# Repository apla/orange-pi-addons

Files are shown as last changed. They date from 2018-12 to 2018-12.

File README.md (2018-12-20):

# Orange Pi Zero+ H5 Addons

## Hacking Addon

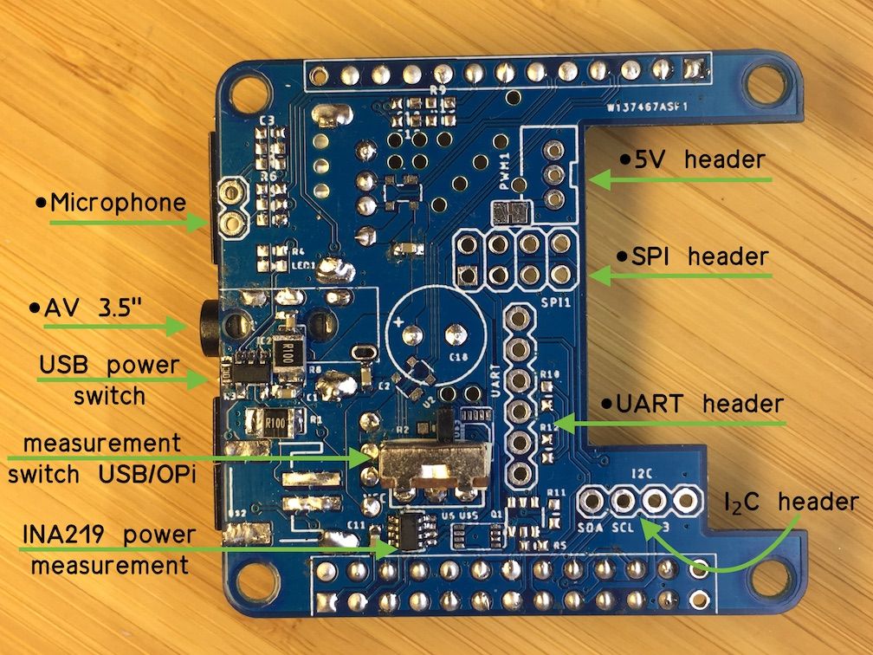
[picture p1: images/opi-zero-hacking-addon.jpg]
Orange Pi Zero Hacking Addon / Shield / Board


## TODO: DeviceTree

[Armbian docs for using overlays](https://docs.armbian.com/User-Guide_Allwinner_overlays/)

https://elinux.org/Device_Tree_Usage

[DTS for OrangePi Zero H2+](https://github.com/torvalds/linux/blob/master/arch/arm/boot/dts/sun8i-h2-plus-orangepi-zero.dts)

[DTS for OrangePi Zero H5](https://github.com/torvalds/linux/blob/master/arch/arm64/boot/dts/allwinner/sun50i-h5-orangepi-zero-plus.dts)

https://forum.armbian.com/topic/8795-next-lts-kernel-419y-allwinner-a10-a20-a64-h2-h3-h5-h6-debugging-party/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

adding voltage regulator

```js
	reg_vdd_cpux: vdd-cpux-regulator {
		compatible = "regulator-gpio";
		regulator-name = "vdd-cpux";
		regulator-type = "voltage";
		regulator-boot-on;
		regulator-always-on;
		regulator-min-microvolt = <1100000>;
		regulator-max-microvolt = <1300000>;
		regulator-ramp-delay = <50>; /* 4ms */

		gpios = <&r_pio 0 6 GPIO_ACTIVE_HIGH>; /* PA6 */
		enable-active-high;
		gpios-states = <0>;
		states = <1100000 0
			  1300000 1>;
	};
```

```js
&cpu0 {
	cpu-supply = <&reg_vdd_cpux>;
};
```

adding usb power switch (https://www.kernel.org/doc/Documentation/devicetree/bindings/regulator/fixed-regulator.txt)

```js
	usb_pwr: usb_pwr {
		compatible = "regulator-fixed";
		regulator-name = "vbus-addon-supply";
		regulator-min-microvolt = <5000000>;
		regulator-max-microvolt = <5000000>;
		gpio = <&r_pio 0 7>;
		regulator-boot-on;
	};
```

[ina219 dt overlay](https://github.com/armbian/sunxi-DT-overlays/blob/master/examples/i2c-ina219.dts)

```js
/dts-v1/;
/plugin/;

/ {
	compatible = "allwinner,sun4i-a10", "allwinner,sun7i-a20", "allwinner,sun8i-h3", "allwinner,sun50i-a64", "allwinner,sun50i-h5";

	fragment@0 {
		target = <&i2c0>;
		__overlay__ {
			#address-cells = <1>;
			#size-cells = <0>;
			ina219@40 {
				compatible = "ti,ina219";
				reg = <0x40>;
				status = "okay";
				shunt-resistor = <100000>;
			};
		};
	};
};
```

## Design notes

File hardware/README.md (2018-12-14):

# HW status: your OPi will burn with flames!

## Hardware issues after manufacture

 * **MAJOR** There is a one short circuit between 5V and GND on USB connector shield
 * 3.5 AV connector placed upside down
 * Current shunt placed after USB, so current meter shows junk after USB power shut down
 * No filtering capacitors for temp and security devices

## What works

 * I2C works fine
 * USB works fine (data, power switching, power metering)

## What untested

 * ESD on USB
 * USB overcurrent indicator
 * UART + UART level shift
 * SPI
 * AV, Mic
 * PWM

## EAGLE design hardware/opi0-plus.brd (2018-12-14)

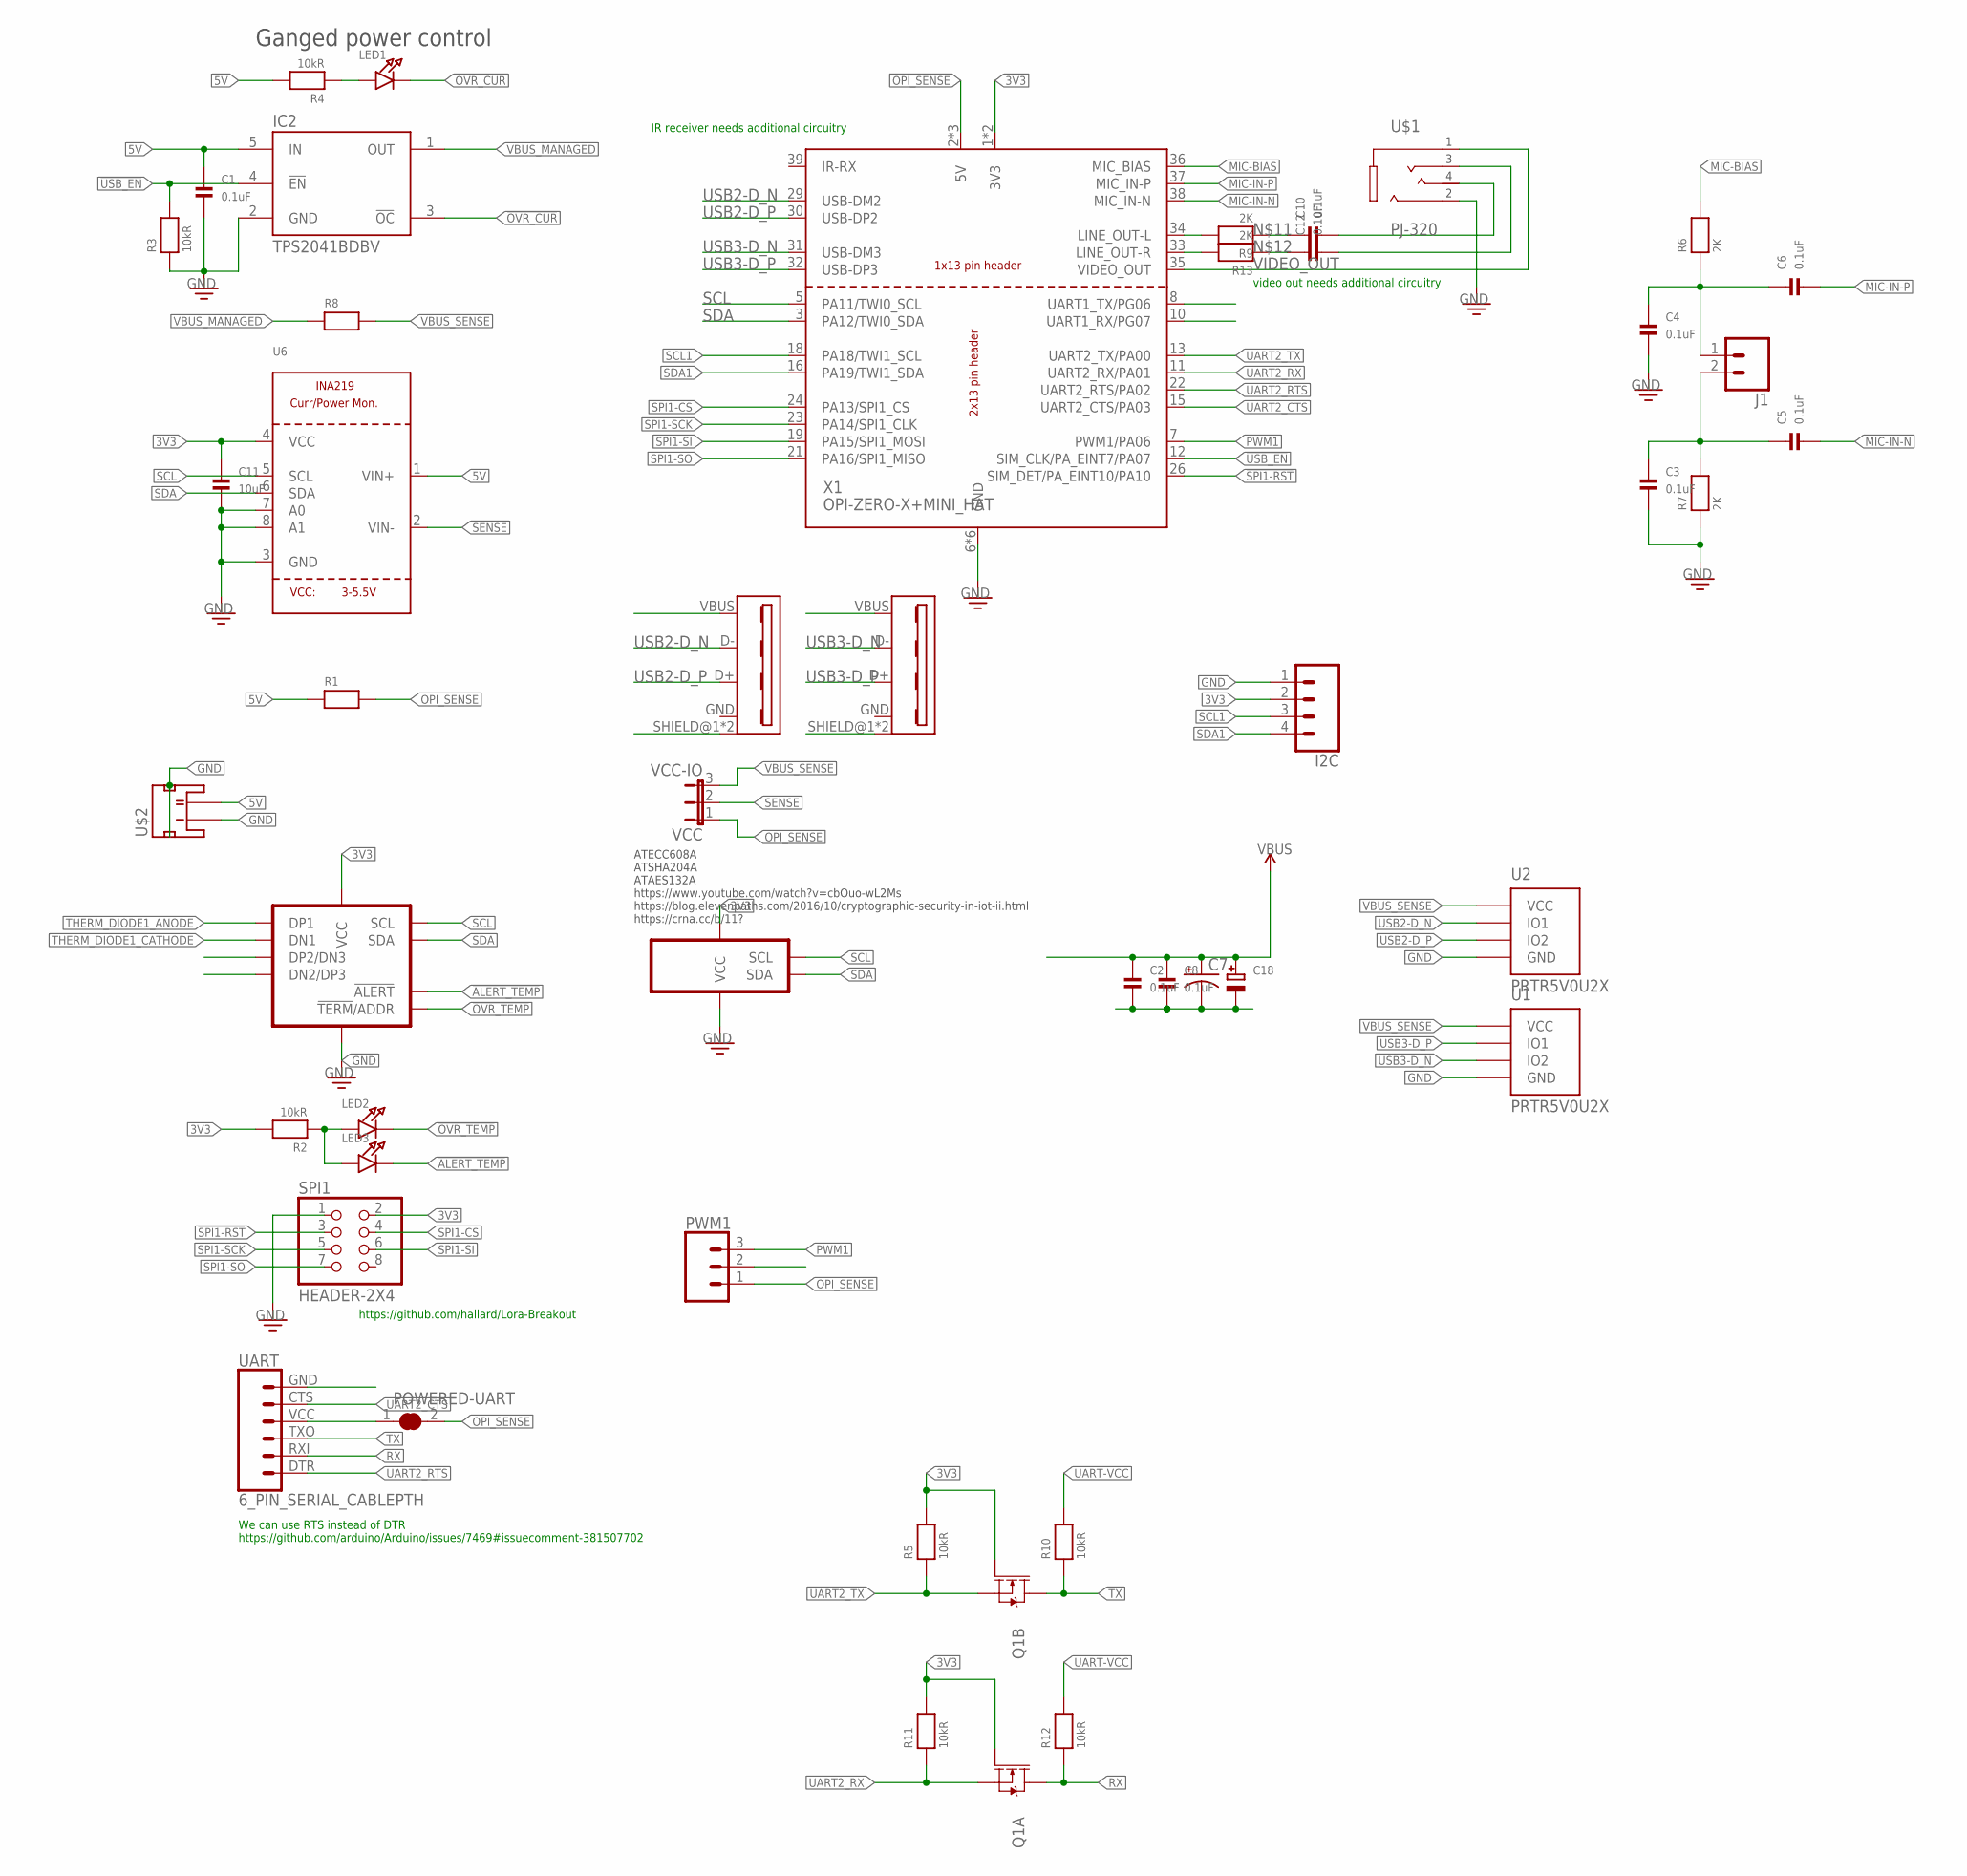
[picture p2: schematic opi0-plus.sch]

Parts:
C1, C2, C3, C4, C5, C6, C8, C10, C12: 0.1uF; _0603MP
C7: CAP_POLD; PANASONIC_D
C11: 10uF; _0603MP
C18: CAP_ELECTROLYTICPTH_3.5MMGRID_8MMDIA; CELEC_3.5MM_8MM
I2C: CONN_04; 1X04
IC2: TPS2041BDBV; SOT23-5L
J1: CONN_02; 1X02
LED1, LED2, LED3: LED0603_NOOUTLINE; CHIPLED_0603_NOOUTLINE
POWERED-UART: SOLDERJUMPER_CLOSED; SOLDERJUMPER_CLOSEDWIRE
PWM1: CONN_03JST-PTH-VERT; JST-3-PTH-VERT
Q1: MOSFET_NCH_DUAL-IRF5852; SOT23-6
R1, R8: RESISTOR1206; 1206
R2, R3, R4, R5, R10, R11, R12: 10kR; _0603MP
R6, R7, R9, R13: 2K; _0603MP
SPI1: HEADER-2X4; 2X04
U1, U2: PRTR5V0U2X; SOT-143B
U6: INA219; SOT23-8
U$1: PJ-320
U$2: JST-PH-2P; JST-PH-SMD
U$3: MCP9904; VDFN-10-0.5-3X3
U$5: ATECC508A-MAH; UDFN-8-0.5-3X2
UART: 6_PIN_SERIAL_CABLEPTH; FTDI_BASIC
USB1, USB2: USB-A-FA-F-PTH; USB-A-F-PTH
VCC: VCC-IO; JUMPER3
X1: OPI-ZERO-X+MINI_HAT; OPI0+MINI_HAT

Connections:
3V3: C11.1, I2C.2, Q1.1 (G), Q1.3 (G), R2.2, R5.2, R11.2, SPI1.2, U6.4 (VCC), U$3.P1 (VCC), U$5.P8 (VCC), X1.1 (3V3), X1.17 (3V3)
5V: C1.1, IC2.5 (IN), R1.1, R4.2, U6.1 (VIN+), U$2.2
!ALERT_TEMP: LED3.C, U$3.P8 (!ALERT)
!OVR_CUR: IC2.3 (!OC), LED1.C
!OVR_TEMP: LED2.C, U$3.P7 (!TERM!/ADDR)
!SPI1-RST!: SPI1.3, X1.26 (SIM_DET/PA_EINT10/PA10)
!USB_EN: IC2.4 (!EN), R3.2, X1.12 (SIM_CLK/PA_EINT7/PA07)
GND: C1.2, C2.2, C3.2, C4.2, C7.-, C8.2, C11.2, C18.-, I2C.1, IC2.2 (GND), PWM1.2, R3.1, R7.1, SPI1.1, U1.1 (GND), U2.1 (GND), U6.3 (GND), U6.7 (A0), U6.8 (A1), U$1.2_1 (2), U$2.1, U$2.SOL@1 (PAD1), U$2.SOL@2 (PAD2), U$3.P6 (GND), U$5.P4 (GND), UART.GND (6), USB1.GND, USB1.SHIELD@1 (SHIELD), USB1.SHIELD@2 (SHIELD), USB2.GND, USB2.SHIELD@1 (SHIELD), USB2.SHIELD@2 (SHIELD), X1.6 (GND), X1.9 (GND), X1.14 (GND), X1.20 (GND), X1.25 (GND), X1.28 (GND)
LINE-L: C10.2, U$1.4_1 (4)
LINE-R: C12.2, U$1.3
MIC-BIAS: R6.2, X1.36 (MIC_BIAS)
MIC-IN-N: C5.2, X1.38 (MIC_IN-N)
MIC-IN-P: C6.2, X1.37 (MIC_IN-P)
unnamed: LED2.A, LED3.A, R2.1
unnamed: C4.1, C6.1, J1.1, R6.1
unnamed: C3.1, C5.1, J1.2, R7.2
unnamed: LED1.A, R4.1
unnamed: R9.2, X1.34 (LINE_OUT-L)
unnamed: R13.2, X1.33 (LINE_OUT-R)
unnamed: C10.1, R9.1
unnamed: C12.1, R13.1
OPI_SENSE: POWERED-UART.2, PWM1.1, R1.2, VCC.1, X1.2 (5V), X1.4 (5V), X1.27 (5V)
PWM1: PWM1.3, X1.7 (PWM1/PA06)
RX: Q1.6 (D), R12.1, UART.RXI (2)
SCL: U6.5 (SCL), U$3.P10 (SCL), U$5.P6 (SCL), X1.5 (PA11/TWI0_SCL)
SCL1: I2C.3, X1.18 (PA18/TWI1_SCL)
SDA: U6.6 (SDA), U$3.P9 (SDA), U$5.P5 (SDA), X1.3 (PA12/TWI0_SDA)
SDA1: I2C.4, X1.16 (PA19/TWI1_SDA)
SENSE: U6.2 (VIN-), VCC.2
SPI1-CS: SPI1.4, X1.24 (PA13/SPI1_CS)
SPI1-SCK: SPI1.5, X1.23 (PA14/SPI1_CLK)
SPI1-SI: SPI1.6, X1.19 (PA15/SPI1_MOSI)
SPI1-SO: SPI1.7, X1.21 (PA16/SPI1_MISO)
THERM_DIODE1_ANODE: U$3.P2 (DP1)
THERM_DIODE1_CATHODE: U$3.P3 (DN1)
TX: Q1.4 (D), R10.1, UART.TXO (3)
UART2_CTS: UART.CTS (5), X1.15 (UART2_CTS/PA03)
UART2_RTS: UART.DTR (1), X1.22 (UART2_RTS/PA02)
UART2_RX: Q1.5 (S), R11.1, X1.11 (UART2_RX/PA01)
UART2_TX: Q1.2 (S), R5.1, X1.13 (UART2_TX/PA00)
UART-VCC: POWERED-UART.1, R10.2, R12.2, UART.VCC (4)
USB2-D_N: U2.2 (IO1), USB1.D-, X1.29 (USB-DM2)
USB2-D_P: U2.3 (IO2), USB1.D+, X1.30 (USB-DP2)
USB3-D_N: U1.3 (IO2), USB2.D-, X1.31 (USB-DM3)
USB3-D_P: U1.2 (IO1), USB2.D+, X1.32 (USB-DP3)
VBUS_MANAGED: IC2.1 (OUT), R8.1
VBUS_SENSE: C2.1, C7.+, C8.1, C18.+, R8.2, U1.4 (VCC), U2.4 (VCC), USB1.VBUS, USB2.VBUS, VCC.3
VIDEO_OUT: U$1.1, X1.35 (VIDEO_OUT)

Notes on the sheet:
Ganged power control
We can use RTS instead of DTR https://github.com/arduino/Arduino/issues/7469#issuecomment-381507702
ATECC608A ATSHA204A ATAES132A https://www.youtube.com/watch?v=cbOuo-wL2Ms https://blog.elevenpaths.com/2016/10/cryptographic-security-in-iot-ii.html https://crna.cc/b/11?
https://github.com/hallard/Lora-Breakout
video out needs additional circuitry
IR receiver needs additional circuitry

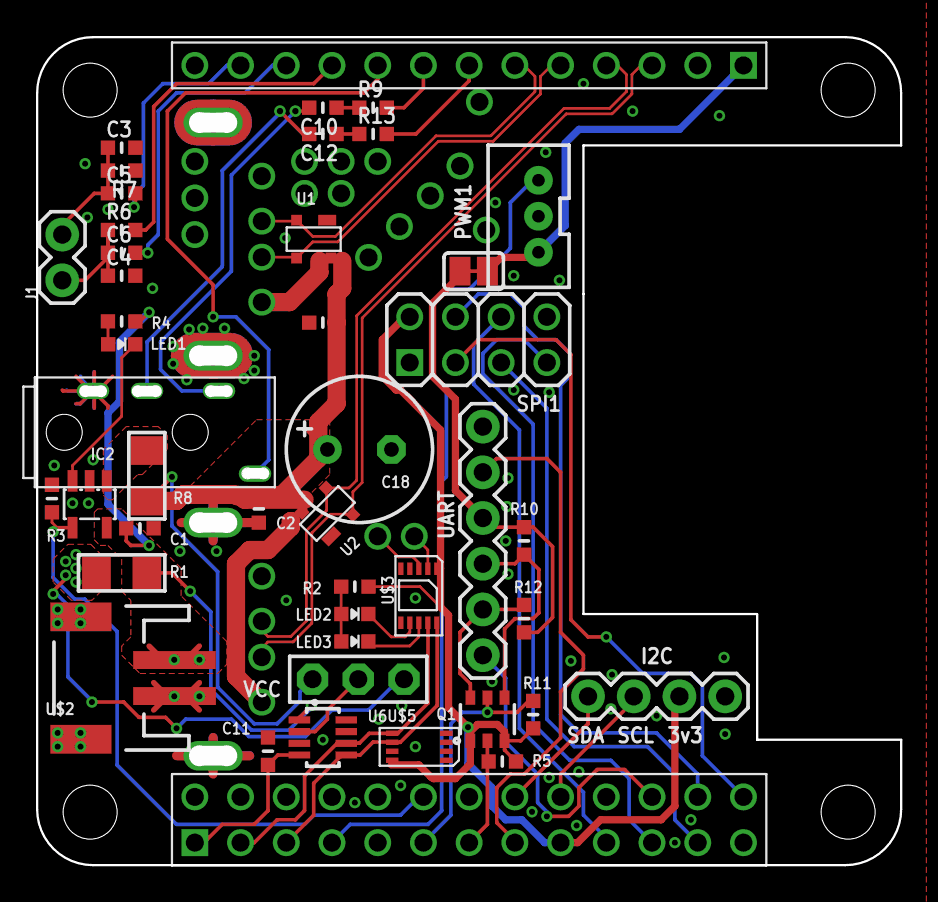
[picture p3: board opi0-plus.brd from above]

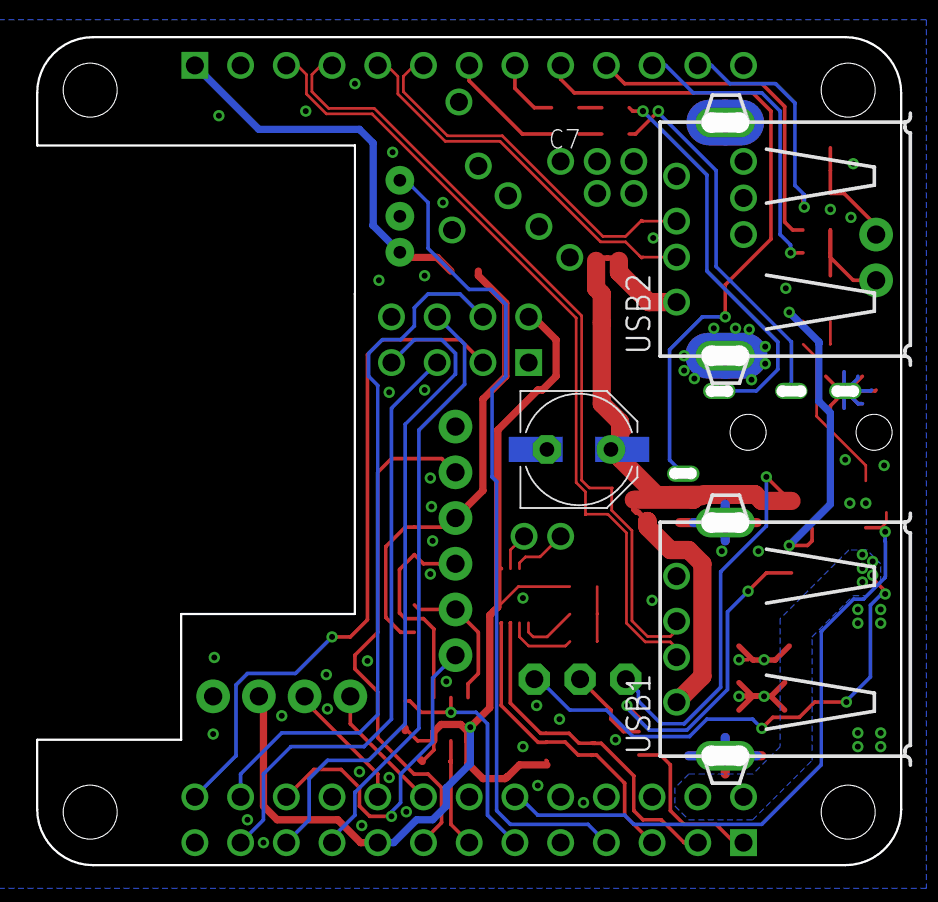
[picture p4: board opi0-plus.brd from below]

Board: 2 copper layers, 48.0 x 46.0 mm, 47 parts (3 on the bottom side), 46 nets.

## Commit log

2018-12-14 initial revision + pcb
    [opi0-plus.brd, opi0-plus.sch]
2018-12-20 addon image with current status

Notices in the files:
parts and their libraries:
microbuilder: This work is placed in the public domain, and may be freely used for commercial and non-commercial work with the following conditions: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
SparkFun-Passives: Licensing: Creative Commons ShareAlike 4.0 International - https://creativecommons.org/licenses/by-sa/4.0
